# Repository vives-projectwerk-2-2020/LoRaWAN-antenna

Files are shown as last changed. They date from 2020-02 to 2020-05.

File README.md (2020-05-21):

# The LoRaWAN-antenna board

This is the explanation of how the antenna PCB board came. And how you can make one yourself.
This PCB described here must then be connected to the main PCB. Below you can see what it looks like.

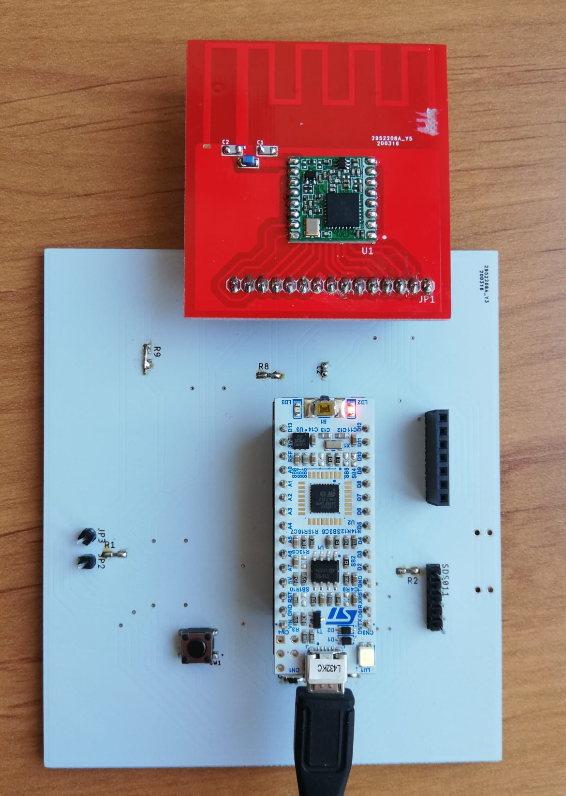
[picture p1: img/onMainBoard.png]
on main board


This Antenna on the board is based on [this](http://www.ti.com/lit/an/swra228c/swra228c.pdf) design.

## Explanation of the Antenna PCB board

Below you see the antenna board. The PCB antenna on this board is suitable for a frequency around 868MHz.

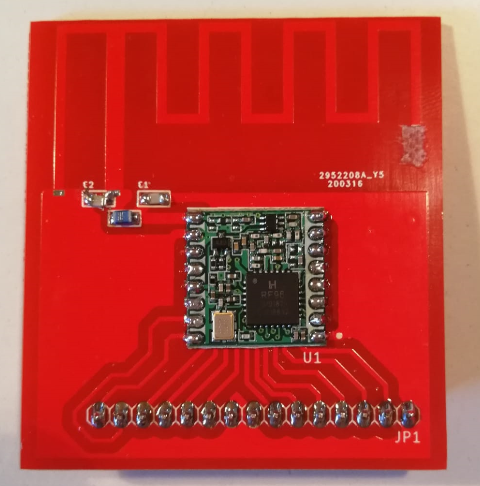
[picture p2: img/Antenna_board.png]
Antenna board


The antenna will work most efficiently if it is resonant. When it is resonant, the maximum power will be radiated by the antenna. If an antenna is not resonant, some of the power will not be transmitted. The power is reflected back to the transmitter (in our case the RF96 module).

Because of the reflection you have a RF power loss and you could damage the RF96 module and also reduce your transmission range.

You can solve this by doing 2 things:

* Adjust the length of the antenna and,
* add a matching network.

This is discussed below here.

### Adjust length

You can adjust the length here, by scratching away some copper at the end of the antenna. The total length of the last piece of the antenna is 1,25 cm (measured from the outer corner). See the image below for clarification.

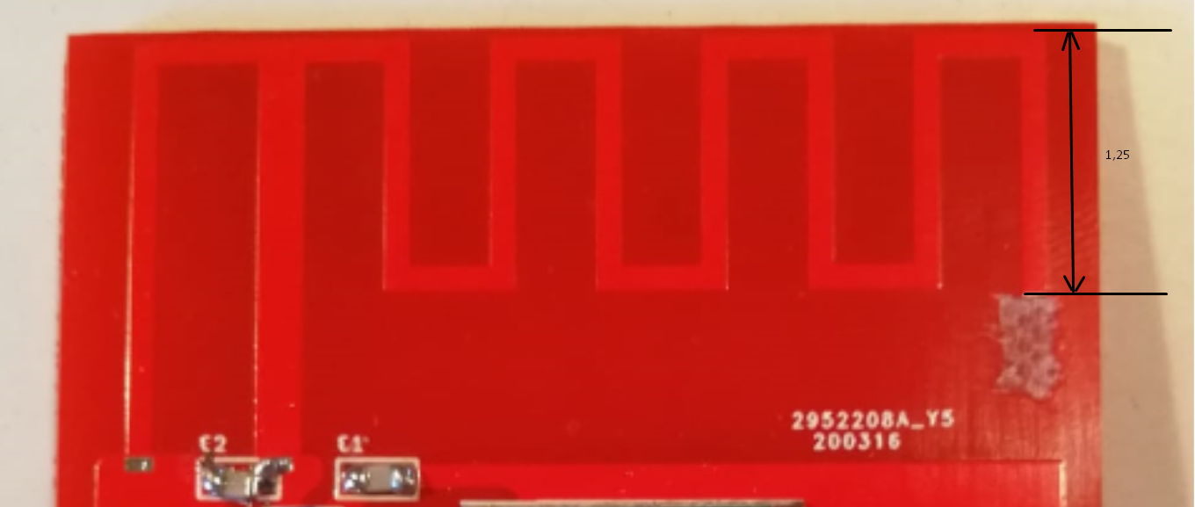
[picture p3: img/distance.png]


By adjusting the length of the antenna, the antenna is now al more suitable for 868MHz.

### Matching network

By adding a matching network now, we can improve the impedance of the antenna more.

The network for adjusting the impedance is a PI network. Below you can see the schematic of the network. The left side of the math unit is connected to the RF96 (the antenna output = pin 9). The right side of the unit is connected to the antenna.

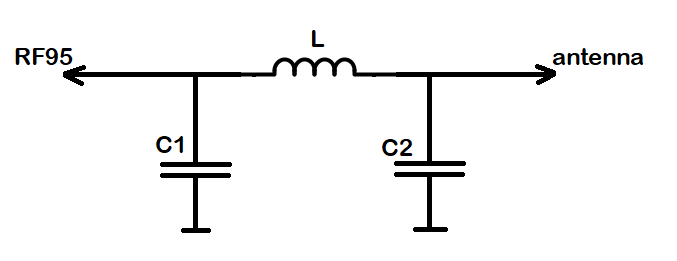
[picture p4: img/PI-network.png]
PI-network


You can observe the matching network below. This consists of 2 capacitors and 1 coil. The values of the capacitors are 2,2pF. The value of the coil is 12nH.

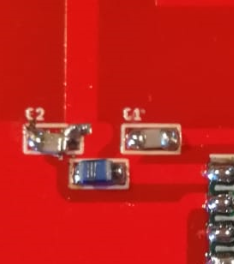
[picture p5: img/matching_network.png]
matching network


Due to mismatches in impedance, some of the signal is reflected. The ratio of the input to the reflected signal is called the Voltage Standing Wave Ratio (VSWR). This ratio can also be measured in dB, and expressed as Return Loss.

Below you can see that the VSWR at 868MHz is 1.112. This mean that you're return lose is 25.510dB. This is very good, because now less than 1% of the power goes back to the module. This means that more than 99% of the power is used for the communication.

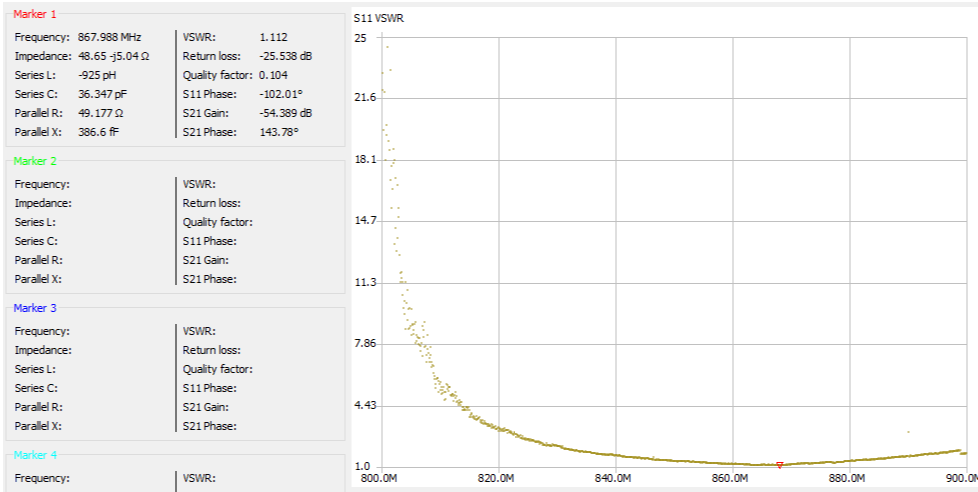
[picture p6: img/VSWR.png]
VSWR


The dimensions of the PCB are also very important. If the dimensions are different from here, you must again determine the length and the matching network.

### RF96

The RF96 module is a module suitable for ultra-long range spread spectrum communications. This module has a 20 dBm power amplifier. This means that you have an output power of 100mW. Because the impedance is now correct, all power will also be radiated effectively.

Below you see the RF95 module. All pins are brought out through the pins. Except the pin that goes to the antenna.
This PCB is then clicked on the main PCB.

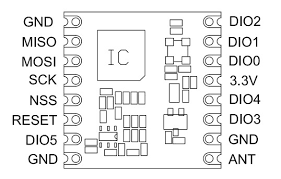
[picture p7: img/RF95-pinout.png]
RF95 pinout


### schematic and print in Eagle

Here you can see the schematic drawn in Eagle. At the top you see the pins, these are then connected to the main PCB. below that you see the RF96 chip.
In the middle you see the matching network, which ensures a correct impedance.
The square block on the right is the symbol for your antenna. It is a symbol whose foodprint is the shape of the antenna.

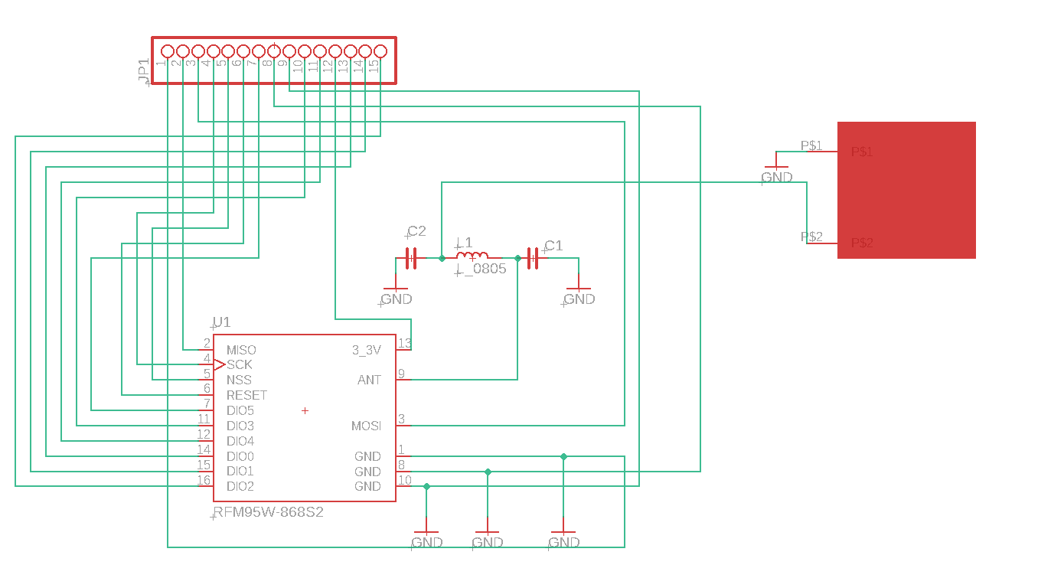
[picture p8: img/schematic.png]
schematic


Below you can see what the PCB looks like in eagle.

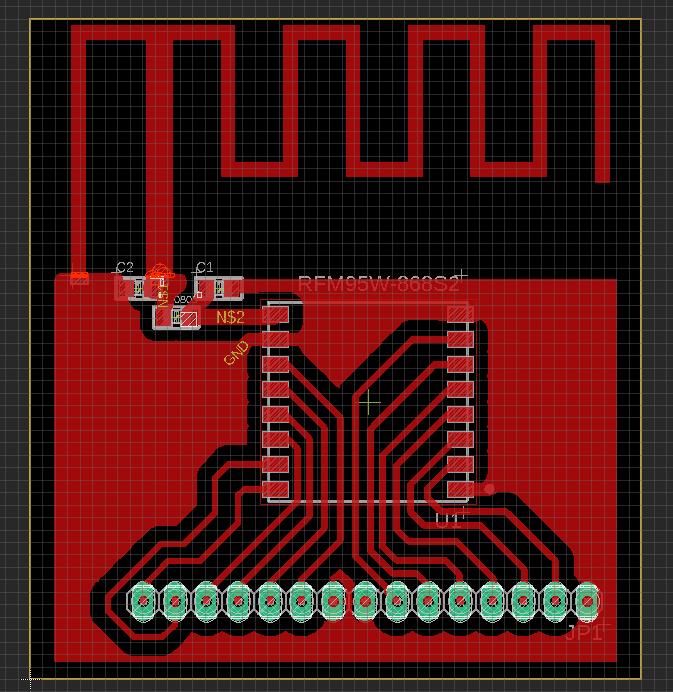
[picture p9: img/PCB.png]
PCB


### tests that happened

You can view the tests that happened in the folder "testing".

## Make it yourself

### Develop the PCB

First you need to develop the PCB. You can do this by sending a zip to a manufacturer. Like for example with this manufacturer([JLCPCB](https://jlcpcb.com/)).
The ZIP file is located here in the root and is called 'LoRaWAN_antenna.zip'. You can download and upload this on the manufacturer's website. If you want to make changes to the PCB you can edit it in the folder 'PCB-antenna-eagle'.

### Order the components

Then you have to order the components. These are the components:

* [coil (12nH)](https://be.farnell.com/te-connectivity/36502a12njtdg/inductor-12n-5-0805-case/dp/1265504?st=)
* [capacitors (2.2pF)](https://be.farnell.com/vishay/vj0805a2r2bxapw1bc/cap-2-2pf-50v-c0g-np0-0805/dp/2896503?st=)
* [RF96 module](https://www.digikey.be/product-detail/en/seeed-technology-co.,-ltd/109990166/1597-1488-ND/7033232?utm_adgroup=RF%20Transceiver%20Modules&utm_source=google&utm_medium=cpc&utm_campaign=Shopping_Product_RF%2FIF%20and%20RFID&utm_term=&productid=7033232&gclid=CjwKCAjwqpP2BRBTEiwAfpiD-0hUd9VhSiN13Y9OhOWbJ38YxABk0f2ujbqdI1xJR1xy0auqC77hRBoC65kQAvD_BwE)
* [male pins](https://be.farnell.com/harwin/m20-9990846/connector-header-tht-2-54mm-8way/dp/1022257)

for 1 PCB you need 2 capacitors, 1 coil, 1 RF95 module and 15 male pins.

### Solder everything together

If you then have your PCB and components, you can start soldering.
You should not scratch the antenna anymore, I have already adjusted this in the last version.
For soldering it is best to start with the RF96 module and then the capacitors and the coil.
Then solder the pins on the last.

## Placing the installation

If you have connected all the boards(main + solar + antenna), you can place this where you want.
There are some things to keep in mind:

* Place the installation in a place where connections can be made to a gateway. On [this](https://www.thethingsnetwork.org/map) map you can see where there is a gateway. If you want a map where you can see the range, it is best to use [this map](https://ttnmapper.org/).

* Place the installation as high as possible. The higher, the fewer obstacles in the way and the greater the chance of connecting to a gateway.

* Do not place the antenna under the solar panels or next to the solar panels. Because this will ensure that a lot of your range is gone.

* The box you use should not be made of metal or a substance containing metal. [This](http://www.farnell.com/datasheets/2360495.pdf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) box is ideal. The material from which the box is made is Polycarbonate. This does not contain metal.

* The box with should be placed freely, not against a wall. Also make sure you are at a certain height.

* Make sure the box is not completely closed. It is best to make 1 or 2 small holes at the bottom so that moisture can escape if condensation forms.

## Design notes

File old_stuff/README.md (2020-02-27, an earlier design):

Op PCBs wordt meestal een 4de golf antenne gebruikt, belangrijk hierbij zijn:
* de antenne lengte
* de antenne voeding
* vorm en grootte van het grondvlak en retourpad (hoe groter oppervlak, hoe lager de resonatiefrequentie)
* als de antenne in een plastieken omhulsel geplaatst wordt, dan verlaagd ook de resonatiefrequentie.

De meeste Gateways staan in centrum brugge. Er staat ook 1 op het zwin.
Als er een node in zeebrugge geplaatst wordt, dan is de dichste de gateway aan het zwin (5km)
De antenne van de node moet dus 5 km kunnen overbruggen.

# gevonden ontwerpen:


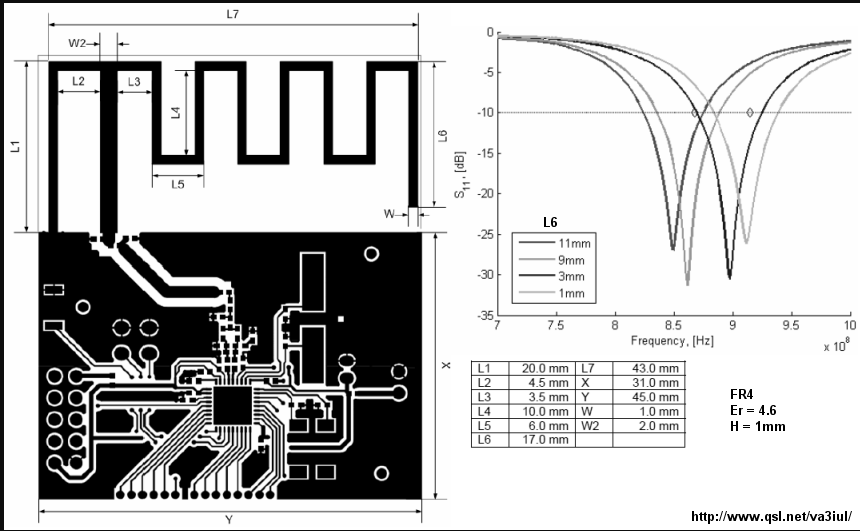
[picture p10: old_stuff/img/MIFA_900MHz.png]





overzicht van verschillende antennes van ti:
http://www.ti.com/lit/an/swra351a/swra351a.pdf

https://www.ti.com/lit/an/swra227e/swra227e.pdf 

http://www.ti.com/lit/an/swra416/swra416.pdf

http://www.ti.com/lit/an/swra228c/swra228c.pdf

https://www.cypress.com/file/136236/download

https://eth0maz.wordpress.com/2016/12/05/lorawan-node-with-onboard-antenna/

Het grootte nadeel aan een PCB antenne is dat het bereik ervan beperkt is. Als er een node wordt opgesteld in zeebrugge moet er zeker 5km overbrugt worden met de antenne. Met een PCB-antenne is dit bijna onmoggelijk.
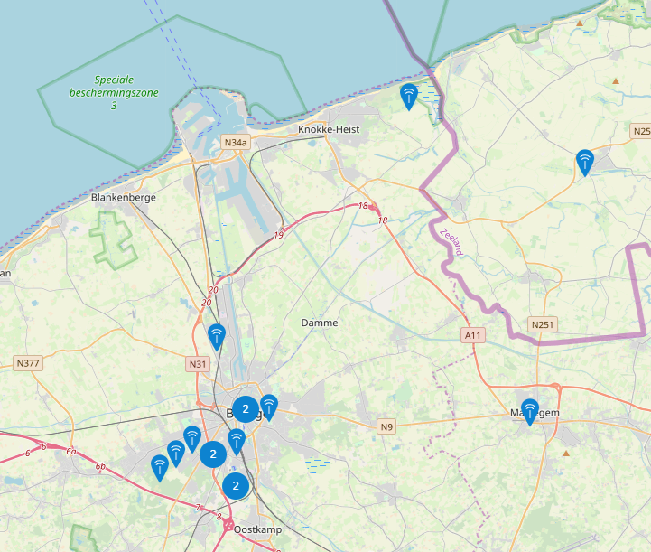
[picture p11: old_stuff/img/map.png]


verschillende soorten PCB antennes:

LOOP
* hoe groter de loop, hoe beter het werkt
* alle omtrekken kleiner dan 0.1 golflengte zijn nutteloos. Voor 868MHz is de golflente 0.35m = 35cm (redelijk groot)
* zeer onefficiënt

PATCH
* breedte van een het vierkant is dicht bij ((golflengte/2)/vierkantswortel van dielectric constant). de breedte zal dus rond de 9cm liggen.
* bandbreedte is zeer smal

INVERTED-F
* groot ground plane nodig

MEANDER LINE
* kleiner bereik

file:///C:/Users/laura/Downloads/Antenna_Reference_Design_Guide_ISM.pdf

Het probleem bij PCB antennes is dat je een richtingseffect krijgt, dat de antenne niet in alle richtingen even goed zal kunnen ontvangen.

PCB antenne: (straalt niet in alle richtingen even veel uit, heeft een richtingseffect)



# dipool: (straalt mooi in alle richtingen evenveel uit)



# biquad antenne: 
stralingspatroon is beter dan van de eerste pcb antenne, dit is niet echt een pcb antenne



op thingiverse staat er een ontwerp dat je kan printen, en dan zelf er een draad in de gleuven legt, maar de afmetingen zijn ook te groot.(https://www.thingiverse.com/thing:2221922 )

# gasket antenne




voordeel: heeft de beste stralingspatroon, van alle platte antennen.

nadeel: moeilijker te tekenen

nadeel:de afmetingen van de antenne zijn te groot, om in de behuizing te plaatsen

-> niet bruikbaar voor onze opstelling.

# koch antenna


# inverted F
* terug te groot voor onze opstelling (20cm breedte, volgens mathlab)

# commercieel
https://www.amazon.co.uk/Lillyelectronics-Q-BAIHE-865-868MHz-Antenna-Connector/dp/B017N761JQ 

# met mahtlab
https://nl.mathworks.com/products/antenna.html

# vereisten
* De radiaton van de antenne moet Omnidirectional zijn, dit wil zeggen dat de antenne in alle richtingen even veel uitzendt/ontvangt. Dit is nodig in ons geval, omdat de gateway overal kan staan.
* De polarizatie van de antenne van de node wordt best verticaal genomen. Dit omdat de meeste gateways ook verticaal werken.
* De bandbreedte, Als de bandbreedte zeer smal is dan is deze zeer moeilijk te maken, maar heb je wel een optimaal ontvangst.
* hoge efficienty, bij een hoge efficienty zijn er niet veel verliezen in de antenne.

file:///C:/Users/laura/Downloads/HF-Praxis7-2015%20V.pdf

http://www.ti.com/lit/an/swra227e/swra227e.pdf

# antenne die zal worden gemaakt worden

http://www.ti.com/lit/an/swra228c/swra228c.pdf
https://github.com/cernohorsky/LoRa-Node

Op deze ontwerpen zal ik mij baseren bij het tekenen en onwerpen van de PCB antenne.

Deze antenne is niet omnidirectioneel, waardoor je een richtingsantenne krijgt. Het is namelijk bijna onmogelijk om een pcb antenne te vinden/ontwikkelen die omnidirectioneel is en nog in de doos zou kunnen.
De afmetingen van deze antenne zijn wel klein genoeg om in de doos te kunnen plaatsen, vandaar de keuze.

## verdere stappen

doorzichtige mika en fotogevoelige printplaat gaan kopen, zodat er kan getest worden als dit ontwerp effectief goed zal werken.
ook de smd condensators aankopen.

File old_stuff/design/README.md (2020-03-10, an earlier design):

# Design about the PCB antenna
## pi-network
Pi-network bestaat uit C3, C4 en L1. (footprint 0805), waarden zullen moeten gemeten worden als de antenna ontworpen is. Dit om ervoor te zorgen dat je een juiste impedantie aanpassing van 50 ohm hebt.



## Eagle schema

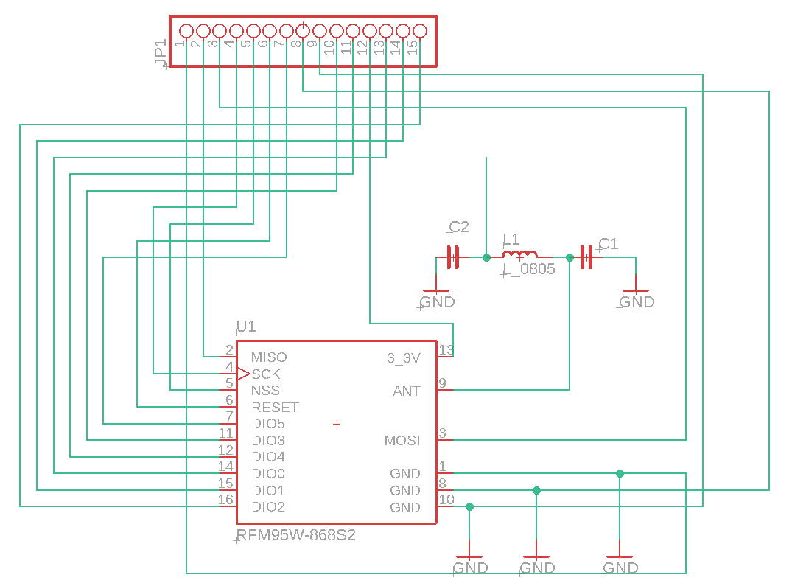
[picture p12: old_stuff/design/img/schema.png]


## Eagle print

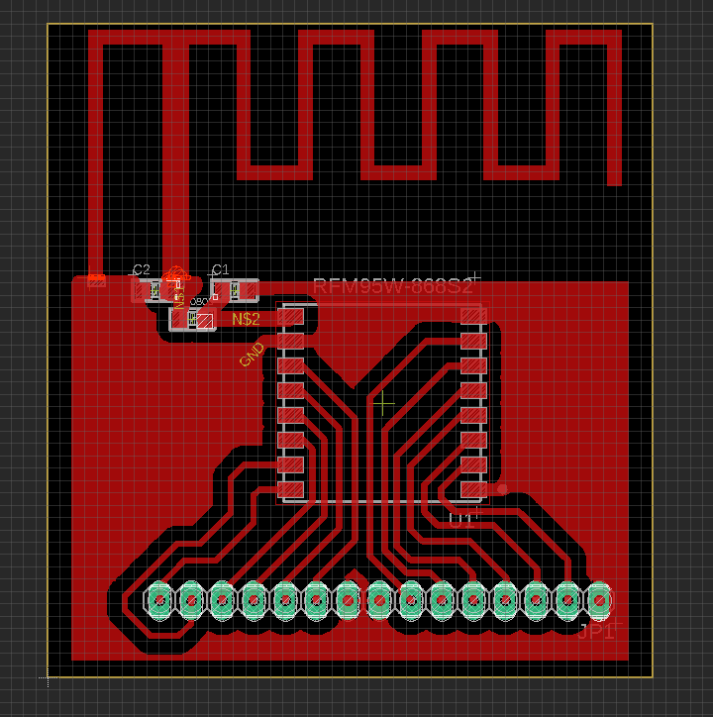
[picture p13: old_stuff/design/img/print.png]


## printen op mika
De transparant maken in mislukt. Er werden verschillende instellingen bij de printer geprobeerd.





Er zal dus een print besteld worden, in plaats van zelf te etsen.

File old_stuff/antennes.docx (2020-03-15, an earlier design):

Hoe dichter het getal VSWR bij ‘1’ is hoe beter dat die antenne is op die frequentie.

S11 (VSWR) | Return loss (dB)
1.001 | 66.025
1.1 | 26.444
1.2 | 20 | 1% reflectie, 99% van het vermogen gaat effectief in de antenne
2.3 | 8 | 16% reflectie, 84% van het vermogen gaat in de antenne
6 | 3 | 50% reflectie, 50% gaat in de antenne
Oneindig (>20) | 0 | 100% reflectie, er gaat geen vermogen in de antenne

je kan ook direct de return loss meten, maar op de S11 grafiek kan je de dalen en pieken mooier zien.

- kleinste antenne
  - 3.121 VSWR

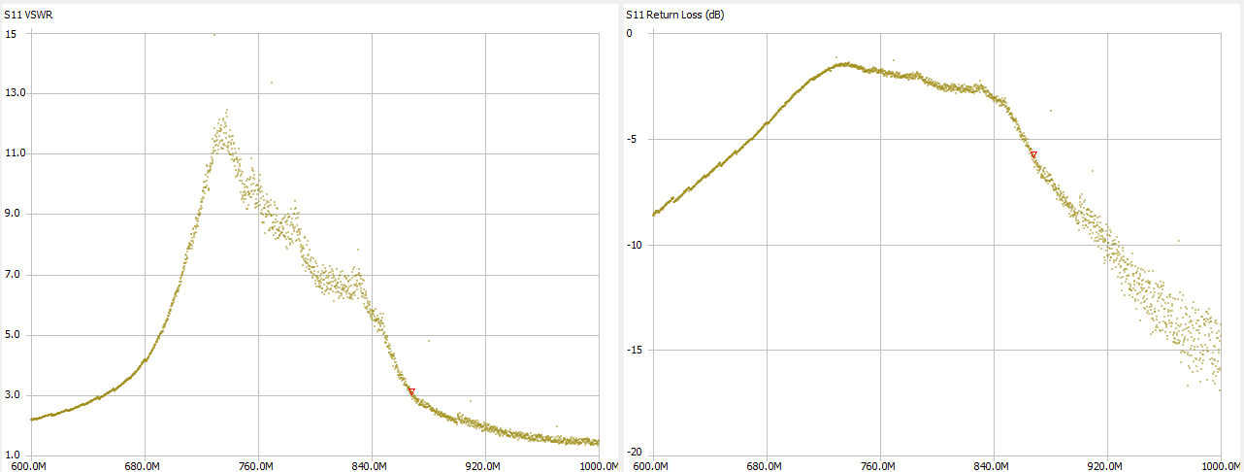
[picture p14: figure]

- kleinste antenne onder een hoek
  - 1.029 VSWR

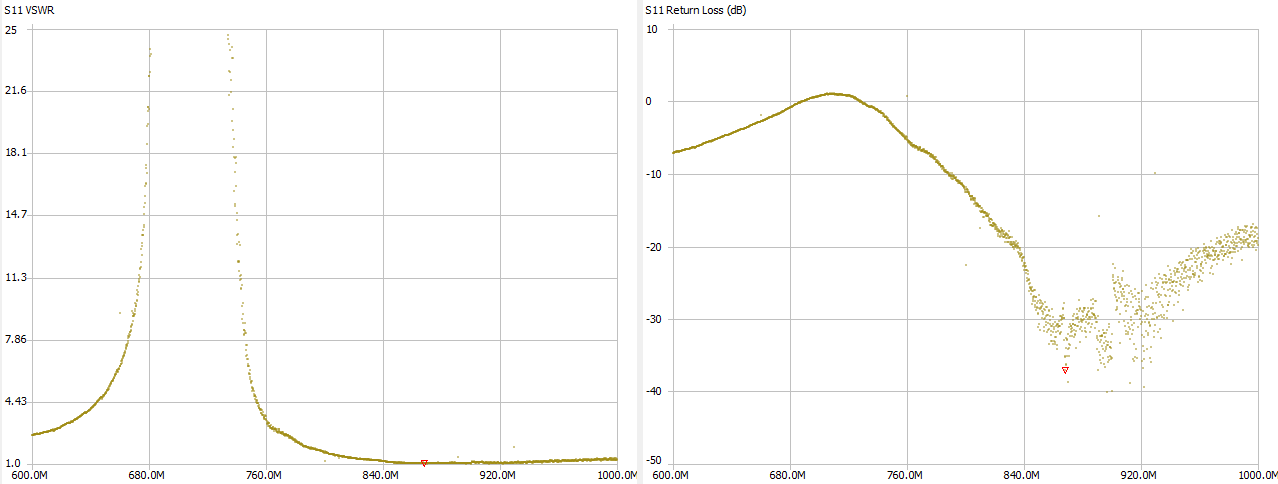
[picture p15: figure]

- 2de kleinste antenne (de fijne)
  - 1.177 VSWR

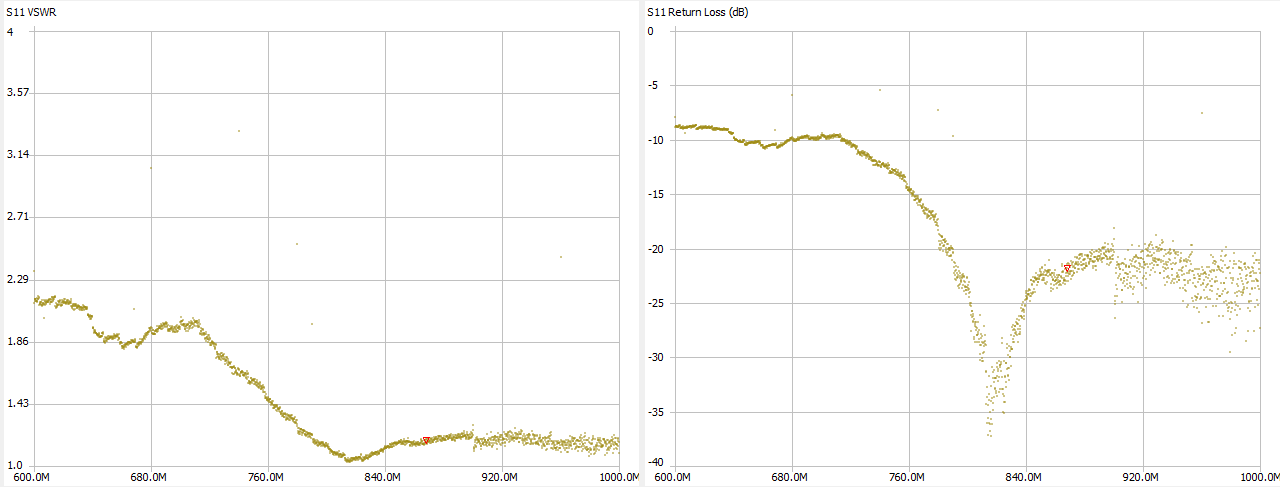
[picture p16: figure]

- 2de kleinste antenne (de dikke)
  - 1.168 VSWR

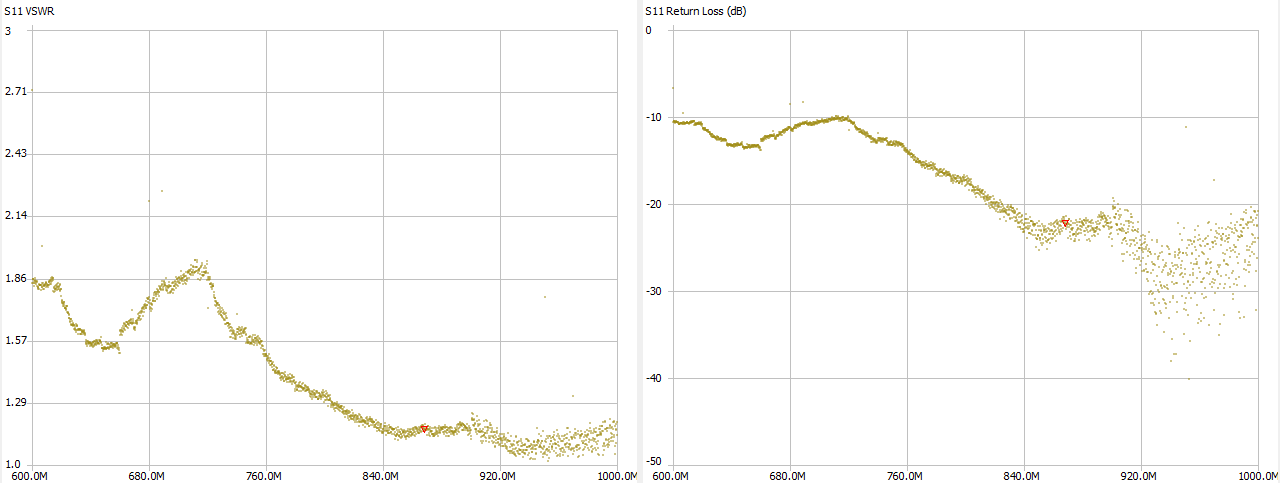
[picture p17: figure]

antenne die op het lorabordje aanwezig was

- -8.655 VSWR

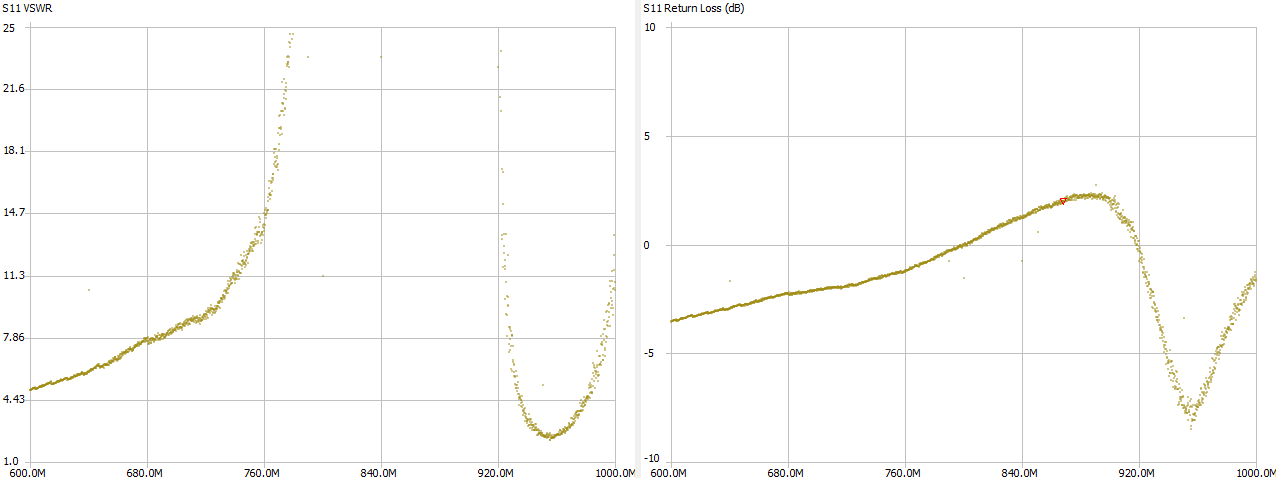
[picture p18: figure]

antenne met 2 rode cirkels vanboven

- 6.655 VSWR

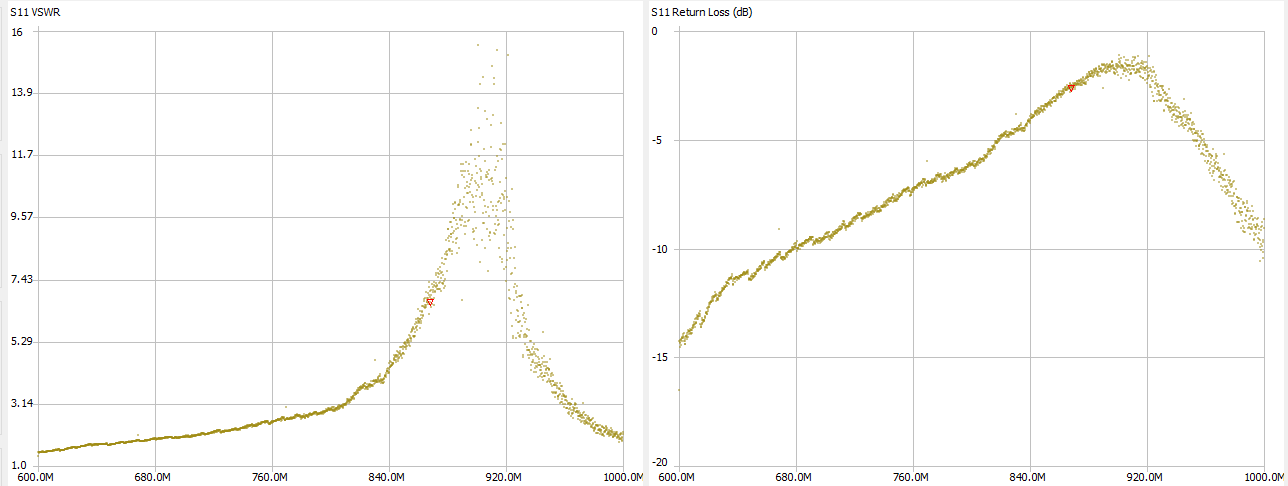
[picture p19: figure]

- 2de grootste antenne
  - 6.235 VSWR

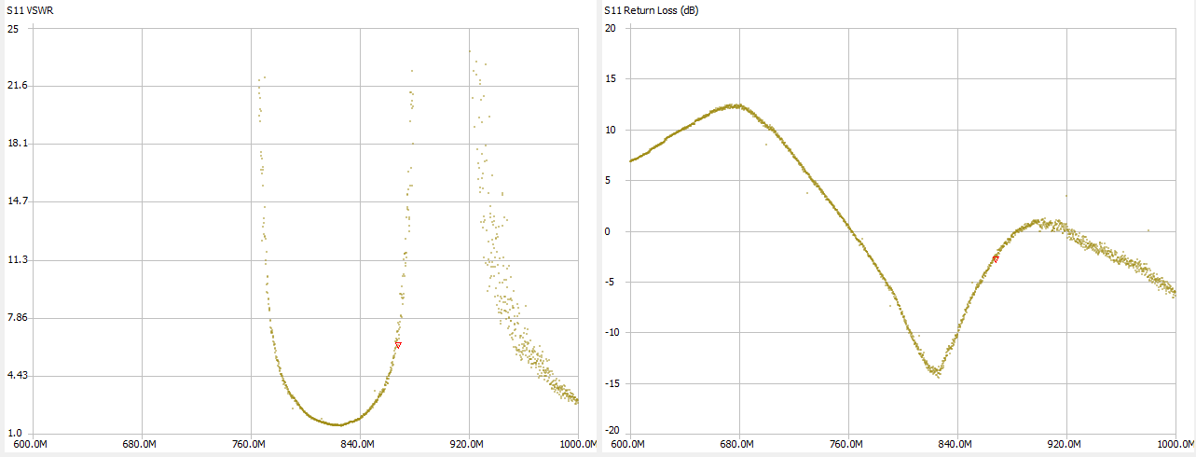
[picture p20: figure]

- grootste antenne
  - 605.667 VSWR = oneindig

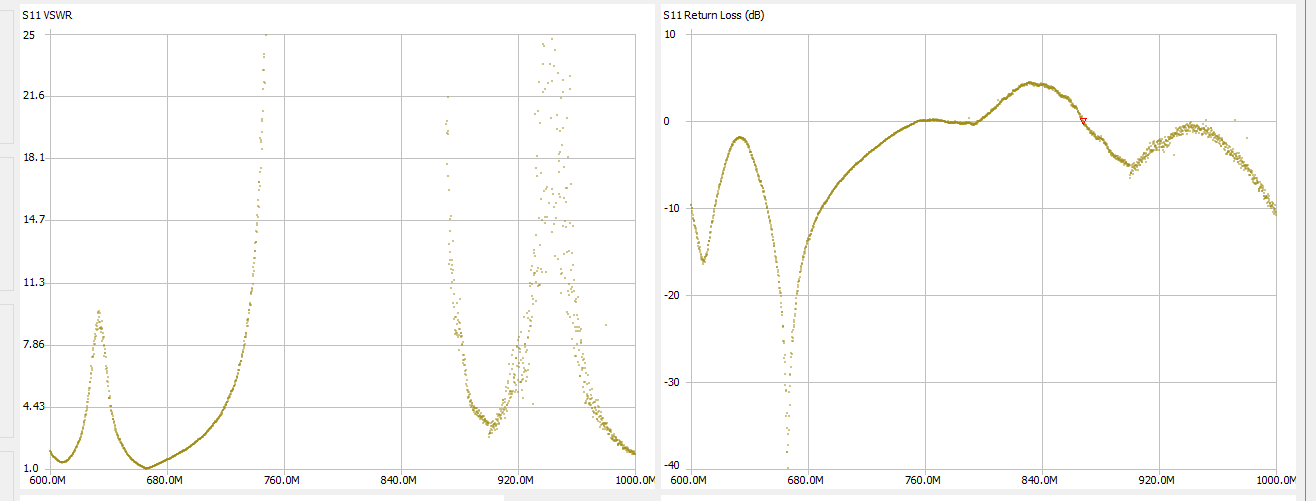
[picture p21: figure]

PCB antenne VSWR

- -2.176 VSWR

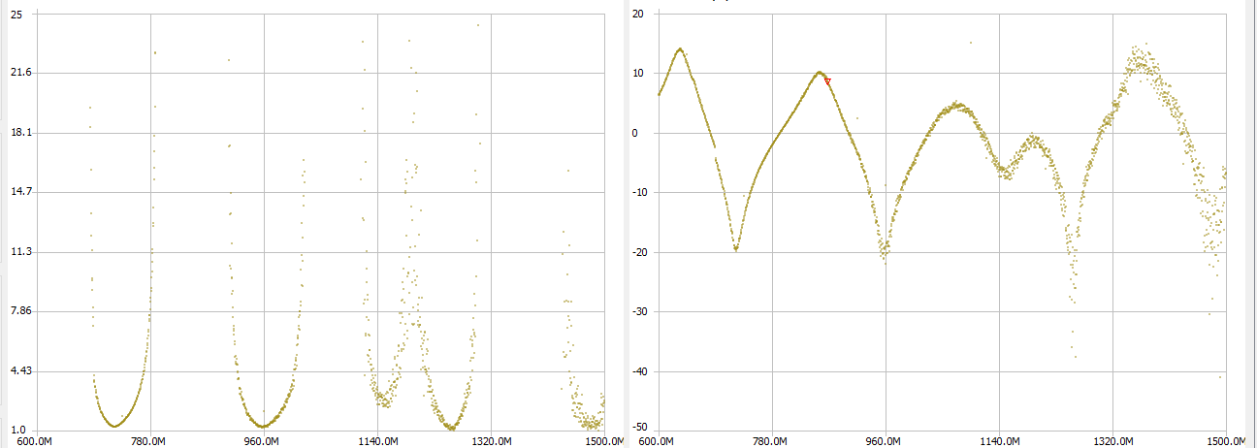
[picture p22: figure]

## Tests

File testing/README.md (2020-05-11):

# TESTING

## Testing the right length and values for the matching network

Soldered on C1 and C2 capacitors of 2.2pF. A value of 12nH was taken for the coil.
The total length of the last piece of the antenna is 1.25 cm. (measured from the outer corner)

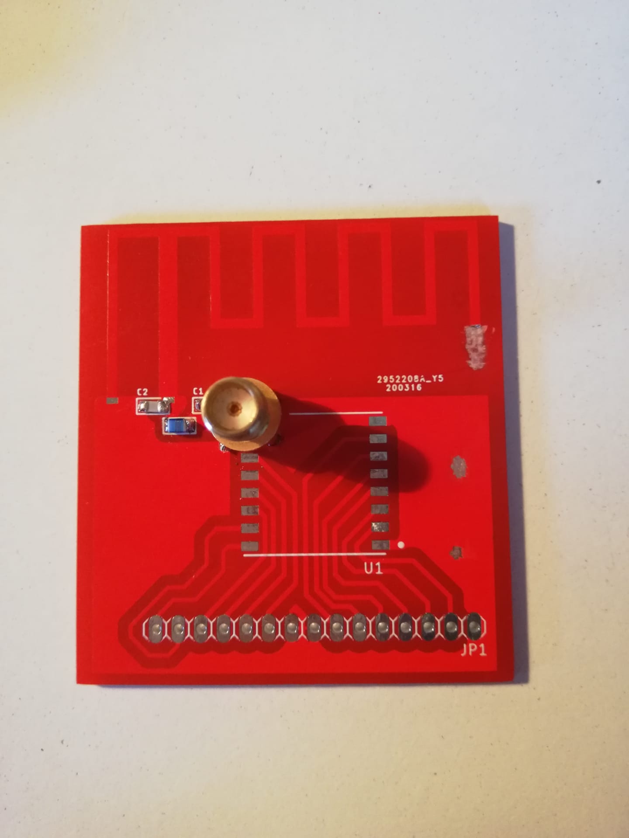
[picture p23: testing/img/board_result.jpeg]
result


In the figure below you can see that at 868MHz the VSWR is 1.112. This is 0.28% reflection of your power sent to your antenna.

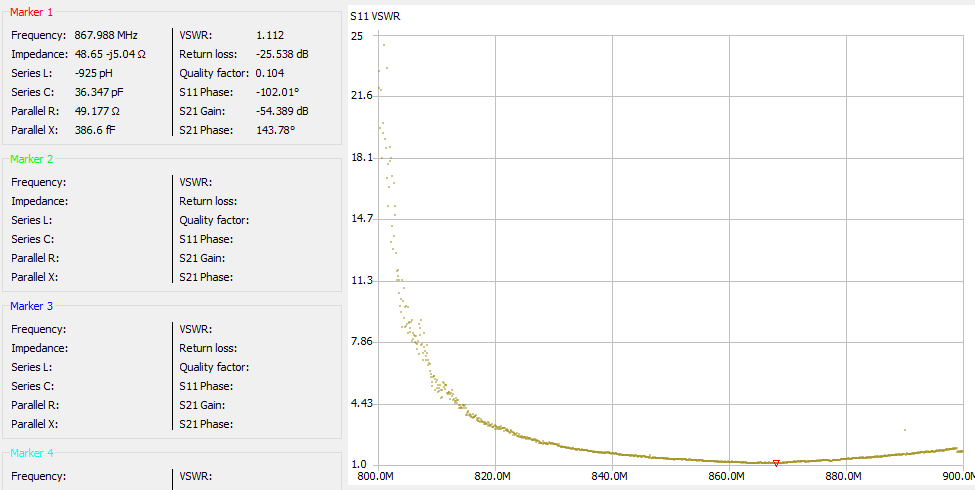
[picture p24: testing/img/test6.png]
test6


## Making the board with lora module

The antenna scratched to the correct length and soldered the components on it.
The pins are properly soldered so that they can be connected to the main board.
This is the frond:

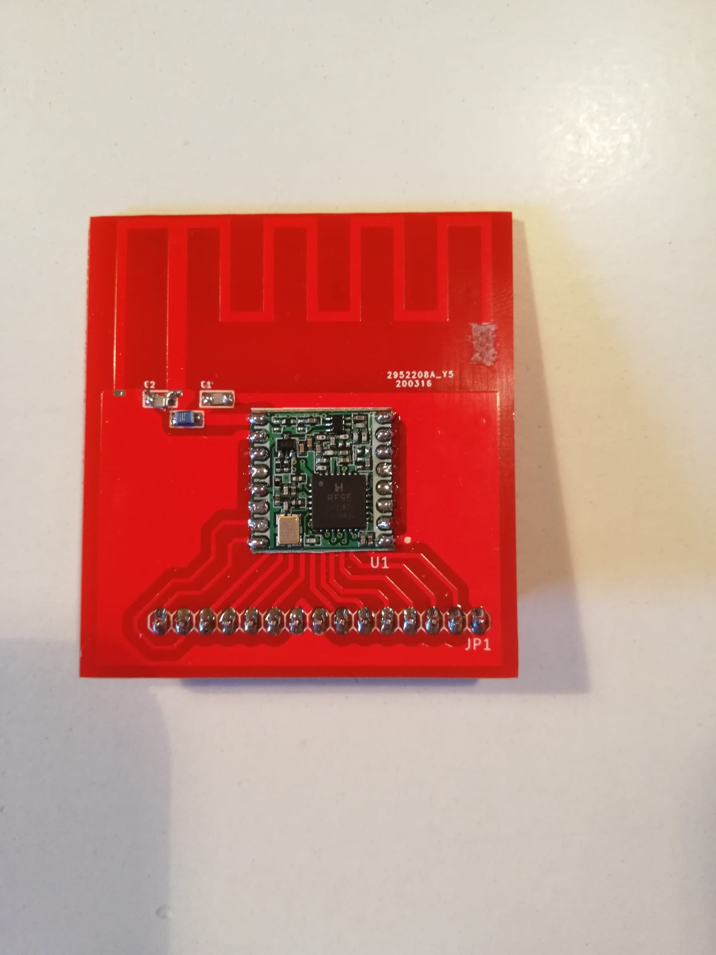
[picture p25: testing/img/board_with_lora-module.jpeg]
front


And this is the back:

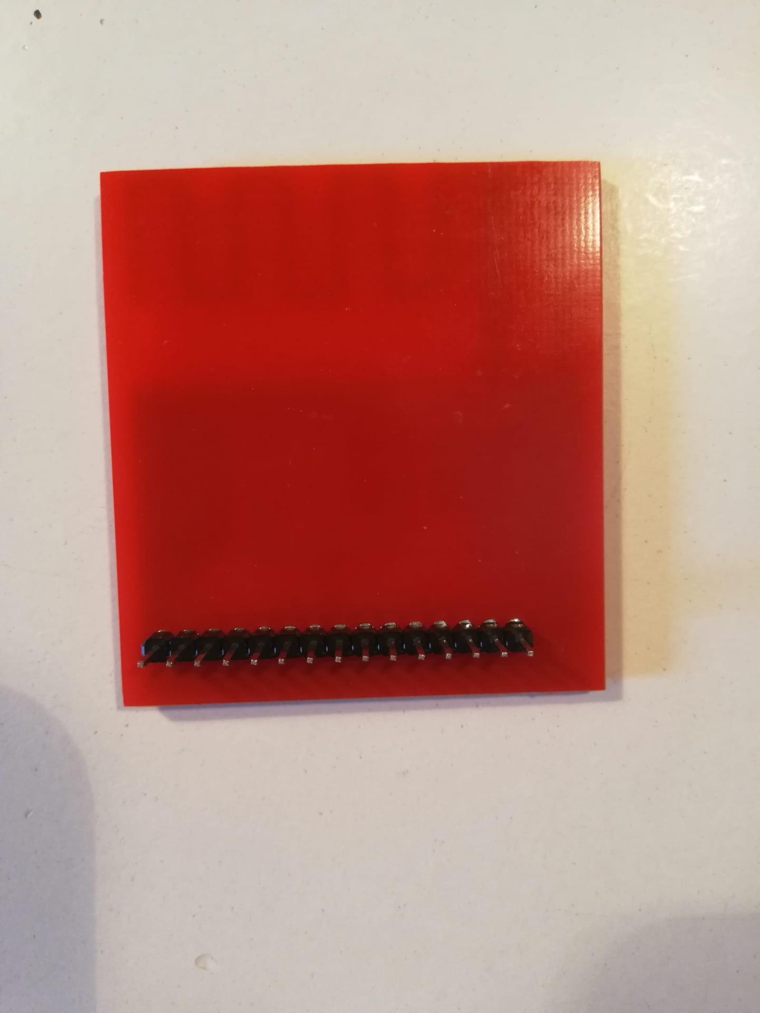
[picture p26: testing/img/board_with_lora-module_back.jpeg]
back


## Testing the board with the main board

The PCB board connected to the main board. Then loaded the software into the Nucleo. The software comes from here: [LoRaWan-example](https://github.com/vives-projectwerk-2-2020/LoRaWAN-example).

In the setting.h something has to be changed about the pins. This is how it should look for the little nucleo:

pins_settings.h

Added a device on TTN and put the keys in a file settings.h as described in the LoRaWan-example.

Here you can see the communication over the port with Putty:

putty

Below you can see that there is a connection with TTN:

status_connection

And here you see 2 boards connected to each other:

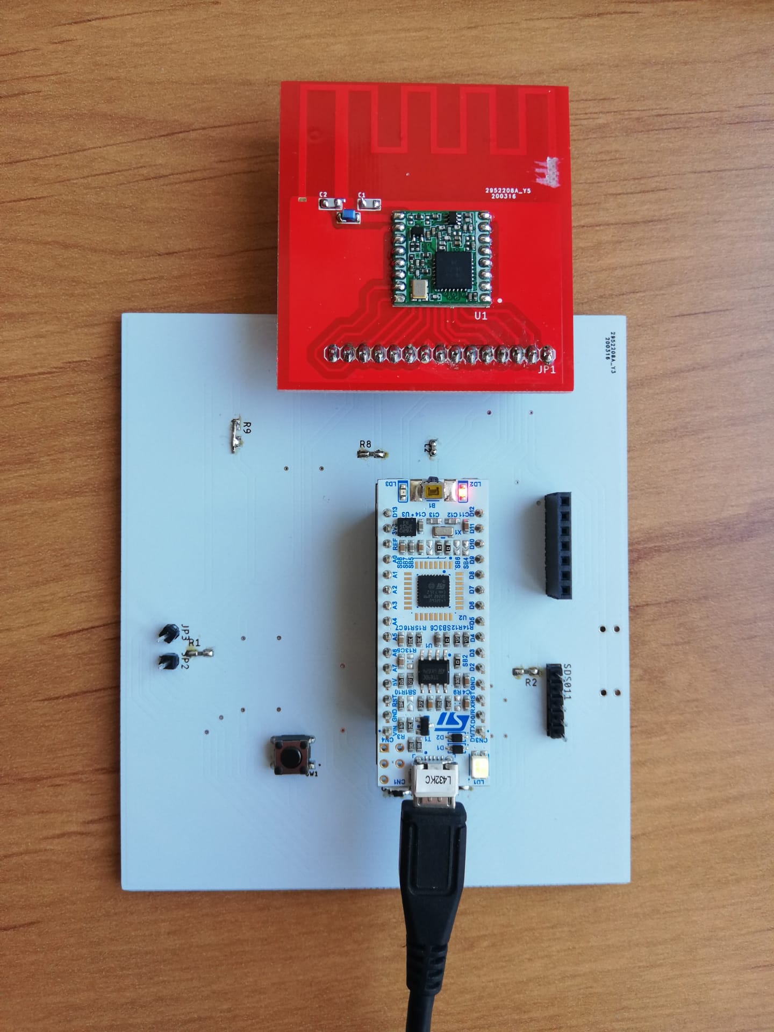
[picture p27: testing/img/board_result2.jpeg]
result


## Test the range with original antennas

On the following images you can see where there was connection with TTN. The gateway I use is a Dragino LG02, at the moment the original antennas are still on it.

point 1: 1,1km. The antennas see each other here.

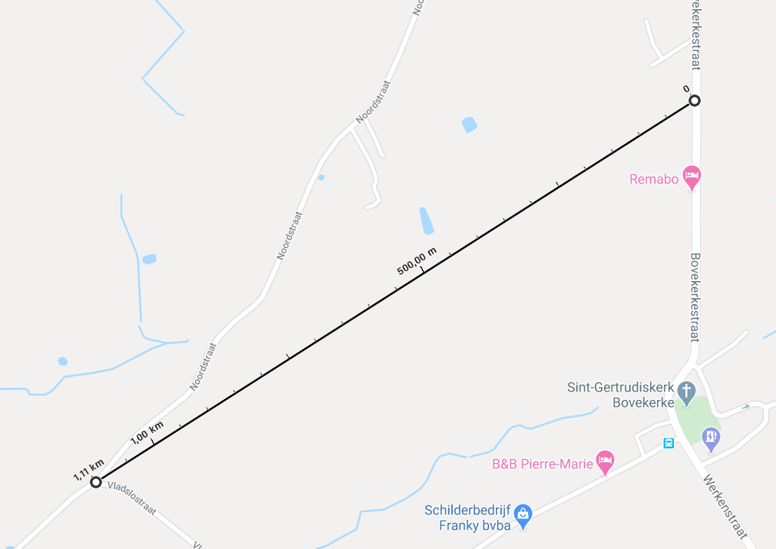
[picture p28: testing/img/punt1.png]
point1


point 2: 1,76km. The antennas did not see each other, there was a large concrete storage place in front of it.

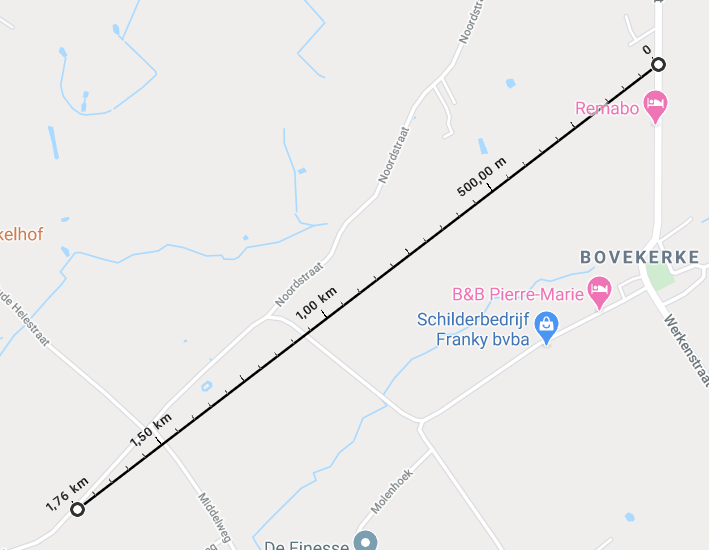
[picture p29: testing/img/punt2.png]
point2


## Test the range with a better antenna on the gateway

The antenna is now 10m high. The test setup can be found in the following 2 images.
In the box is the gateway (LG02 from dragino). One of the original antennas is disconnected and connected to a bigger antenna. This is an omnidirectional antenna with 3dB gain.
The antenna is mounted via a bracket on the pole.

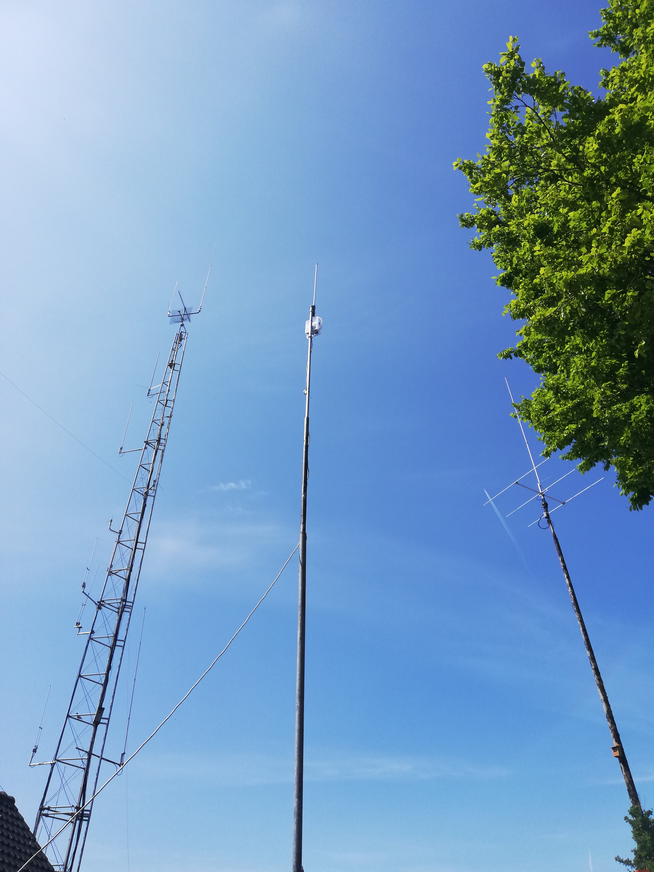
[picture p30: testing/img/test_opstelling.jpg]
test

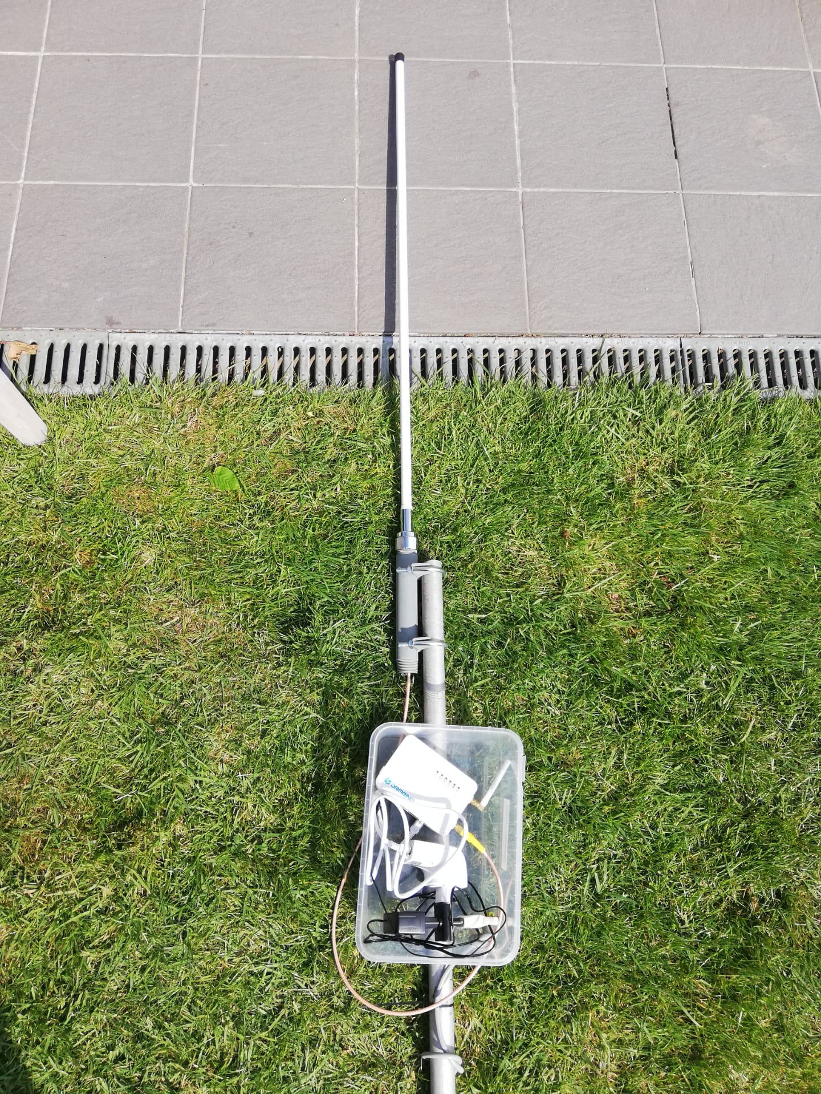
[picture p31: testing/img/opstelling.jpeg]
test


The range is now much better, it is doubled. Distances of 3.20 km are now possible, you can see this on the map below.
The points below are points where connections to TTN could be made. At the points you can always see the distance in bird's eye view.

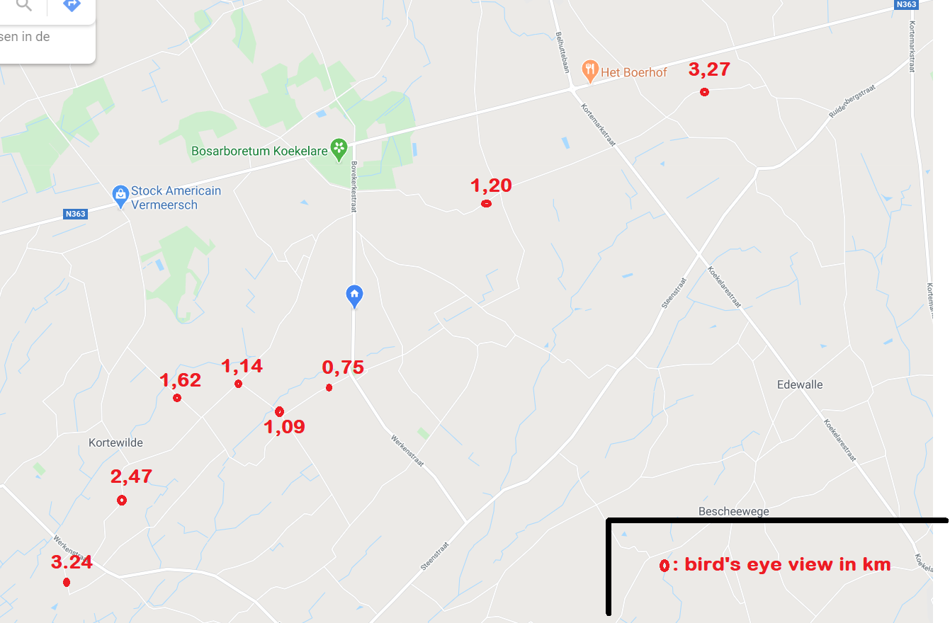
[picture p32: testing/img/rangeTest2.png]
rangeTest2Map


## Test the different between the PCB antenna and the previous antenna

Below you see the circuit:

circuit

Here you can see where there was signal with TTN. You can see that the range with that previous antenna is much smaller.
This means that the PCB antenna is an improvement on the previous antenna.

BadAntenna

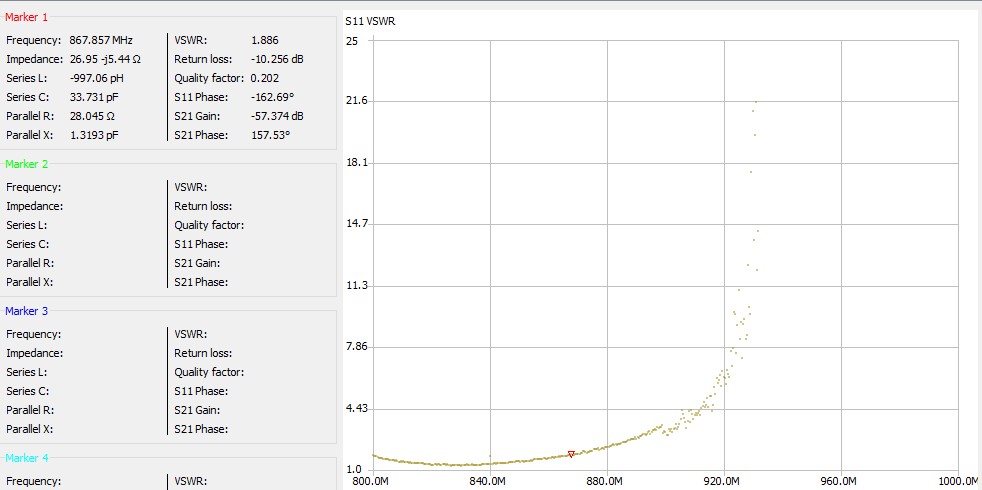
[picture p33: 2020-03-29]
testing/img/test1.png

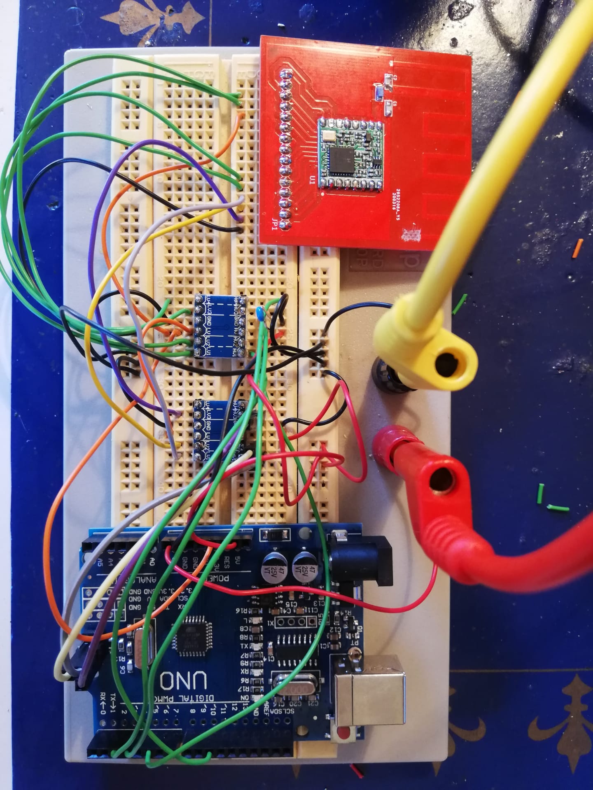
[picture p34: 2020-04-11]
testing/img/arduino.jpeg

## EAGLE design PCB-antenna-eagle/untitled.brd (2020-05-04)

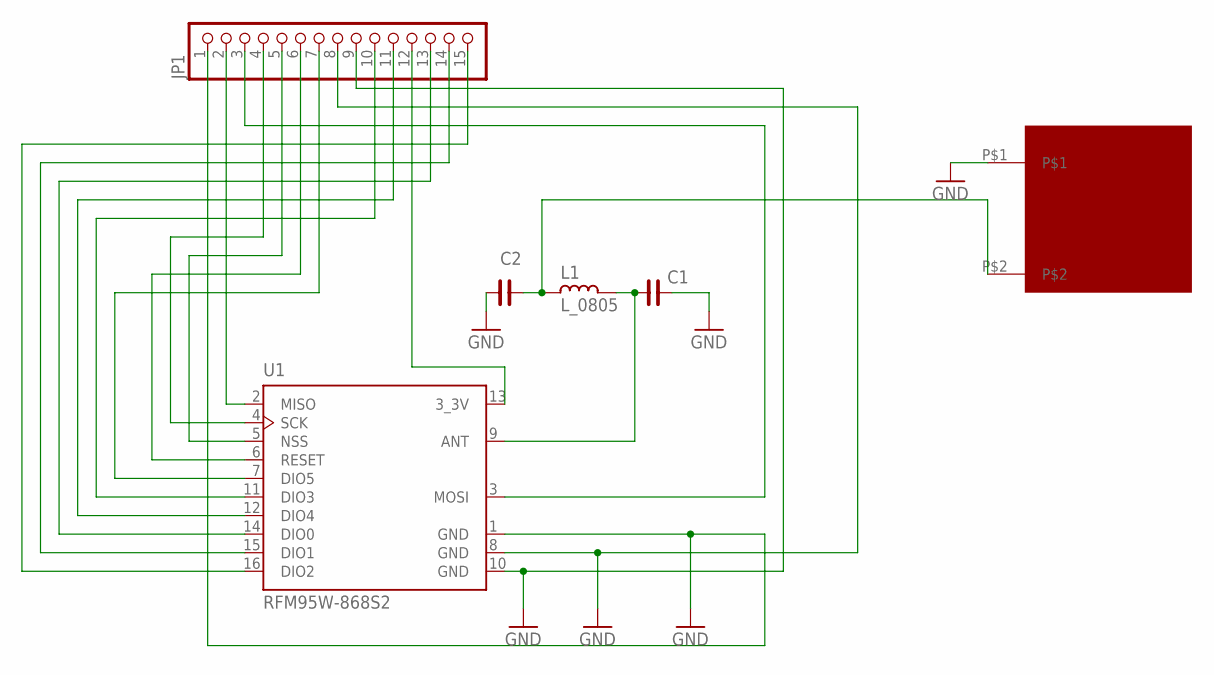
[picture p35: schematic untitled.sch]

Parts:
C1, C2: C_0805; C0805
JP1: PINHD-1X15; 1X15
L1: L_0805; L0805
U1: RFM95W-868S2; XCVR_RFM95W-868S2
U$1: 868

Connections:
GND: C1.2, C2.1, JP1.1, JP1.8, JP1.9, U1.1 (GND), U1.8 (GND), U1.10 (GND), U$1.P$1
unnamed: C2.2, L1.2, U$1.P$2
unnamed: C1.1, L1.1, U1.9 (ANT)
unnamed: JP1.2, U1.2 (MISO)
unnamed: JP1.3, U1.3 (MOSI)
unnamed: JP1.4, U1.4 (SCK)
unnamed: JP1.5, U1.5 (NSS)
unnamed: JP1.6, U1.6 (RESET)
unnamed: JP1.7, U1.7 (DIO5)
unnamed: JP1.10, U1.11 (DIO3)
unnamed: JP1.11, U1.12 (DIO4)
unnamed: JP1.12, U1.13 (3_3V)
unnamed: JP1.13, U1.14 (DIO0)
unnamed: JP1.14, U1.15 (DIO1)
unnamed: JP1.15, U1.16 (DIO2)

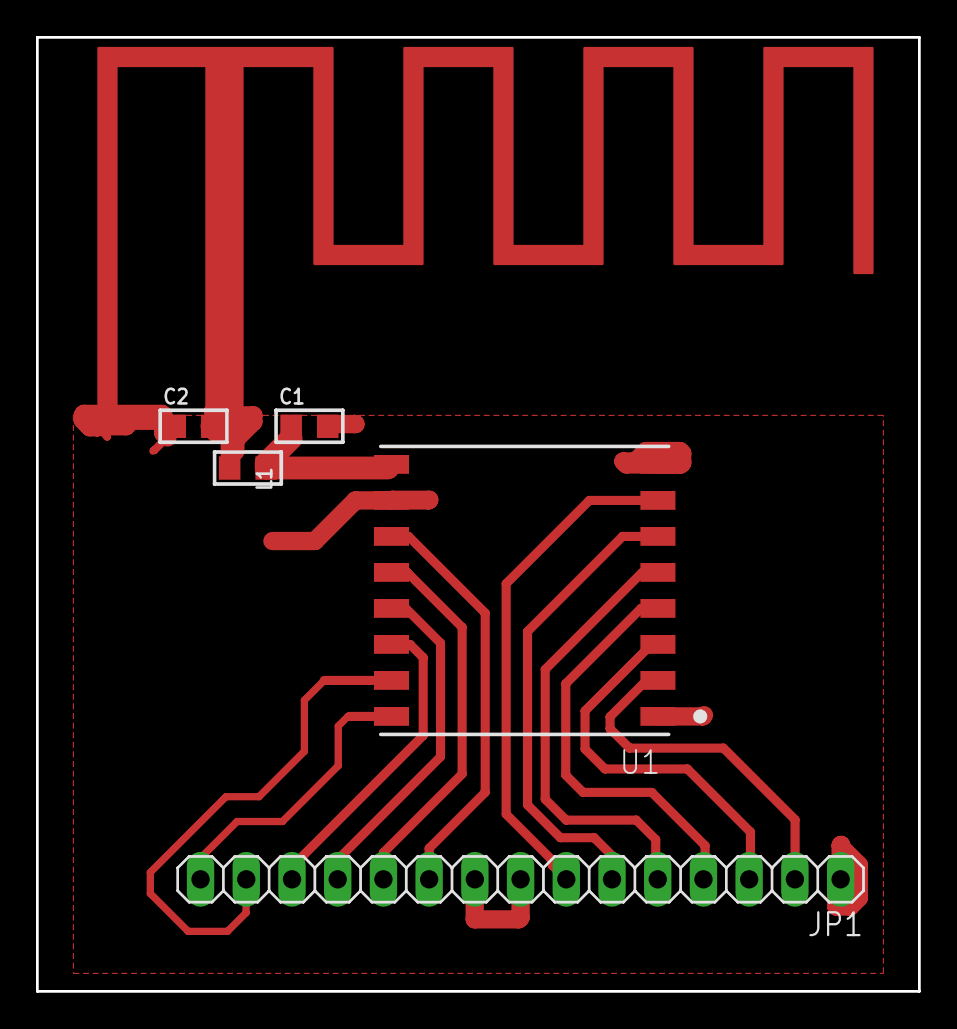
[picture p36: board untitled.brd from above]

Board: 2 copper layers, 49.0 x 53.0 mm, 6 parts (0 on the bottom side), 15 nets.

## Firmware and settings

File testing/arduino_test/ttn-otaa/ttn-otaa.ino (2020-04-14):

/*******************************************************************************
 * Copyright (c) 2015 Thomas Telkamp and Matthijs Kooijman
 * Copyright (c) 2018 Terry Moore, MCCI
 *
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
 * This example sends a valid LoRaWAN packet with payload "Hello,
 * world!", using frequency and encryption settings matching those of
 * the The Things Network.
 *
 * This uses OTAA (Over-the-air activation), where where a DevEUI and
 * application key is configured, which are used in an over-the-air
 * activation procedure where a DevAddr and session keys are
 * assigned/generated for use with all further communication.
 *
 * Note: LoRaWAN per sub-band duty-cycle limitation is enforced (1% in
 * g1, 0.1% in g2), but not the TTN fair usage policy (which is probably
 * violated by this sketch when left running for longer)!

 * To use this sketch, first register your application and device with
 * the things network, to set or generate an AppEUI, DevEUI and AppKey.
 * Multiple devices can use the same AppEUI, but each device has its own
 * DevEUI and AppKey.
 *
 * Do not forget to define the radio type correctly in
 * arduino-lmic/project_config/lmic_project_config.h or from your BOARDS.txt.
 *
 *******************************************************************************/

#include <lmic.h>
#include <hal/hal.h>
#include <SPI.h>

//
// For normal use, we require that you edit the sketch to replace FILLMEIN
// with values assigned by the TTN console. However, for regression tests,
// we want to be able to compile these scripts. The regression tests define
// COMPILE_REGRESSION_TEST, and in that case we define FILLMEIN to a non-
// working but innocuous value.
//
#ifdef COMPILE_REGRESSION_TEST
# define FILLMEIN 0
#else
# warning "You must replace the values marked FILLMEIN with real values from the TTN control panel!"
# define FILLMEIN (#dont edit this, edit the lines that use FILLMEIN)
#endif

// This EUI must be in little-endian format, so least-significant-byte
// first. When copying an EUI from ttnctl output, this means to reverse
// the bytes. For TTN issued EUIs the last bytes should be 0xD5, 0xB3,
// 0x70.
static const u1_t PROGMEM APPEUI[8]={ 0xB0, 0xDA, 0x02, 0xD0, 0x7E, 0xD5, 0xB3, 0x70 };
void os_getArtEui (u1_t* buf) { memcpy_P(buf, APPEUI, 8);}

// This should also be in little endian format, see above.
static const u1_t PROGMEM DEVEUI[8]={ 0xEA, 0xDB, 0xCC, 0xDA, 0x9B, 0x9E, 0xE4, 0x00 };
void os_getDevEui (u1_t* buf) { memcpy_P(buf, DEVEUI, 8);}

// This key should be in big endian format (or, since it is not really a
// number but a block of memory, endianness does not really apply). In
// practice, a key taken from ttnctl can be copied as-is.
static const u1_t PROGMEM APPKEY[16] = { 0xFE, 0x09, 0x57, 0xD2, 0x71, 0x9A, 0x84, 0xBE, 0x05, 0xCF, 0x00, 0x38, 0xF8, 0xC9, 0x1F, 0x32 };
void os_getDevKey (u1_t* buf) {  memcpy_P(buf, APPKEY, 16);}

static uint8_t mydata[] = "Hello, world!";
static osjob_t sendjob;

// Schedule TX every this many seconds (might become longer due to duty
// cycle limitations).
const unsigned TX_INTERVAL = 60;

// Pin mapping
const lmic_pinmap lmic_pins = {
    .nss = 10,
    .rxtx = LMIC_UNUSED_PIN,
    .rst = 5,
    .dio = {2, 3, LMIC_UNUSED_PIN},
};

void printHex2(unsigned v) {
    v &= 0xff;
    if (v < 16)
        Serial.print('0');
    Serial.print(v, HEX);
}

void onEvent (ev_t ev) {
    Serial.print(os_getTime());
    Serial.print(": ");
    switch(ev) {
        case EV_SCAN_TIMEOUT:
            Serial.println(F("EV_SCAN_TIMEOUT"));
            break;
        case EV_BEACON_FOUND:
            Serial.println(F("EV_BEACON_FOUND"));
            break;
        case EV_BEACON_MISSED:
            Serial.println(F("EV_BEACON_MISSED"));
            break;
        case EV_BEACON_TRACKED:
            Serial.println(F("EV_BEACON_TRACKED"));
            break;
        case EV_JOINING:
            Serial.println(F("EV_JOINING"));
            break;
        case EV_JOINED:
            Serial.println(F("EV_JOINED"));
            {
              u4_t netid = 0;
              devaddr_t devaddr = 0;
              u1_t nwkKey[16];
              u1_t artKey[16];
              LMIC_getSessionKeys(&netid, &devaddr, nwkKey, artKey);
              Serial.print("netid: ");
              Serial.println(netid, DEC);
              Serial.print("devaddr: ");
              Serial.println(devaddr, HEX);
              Serial.print("AppSKey: ");
              for (size_t i=0; i<sizeof(artKey); ++i) {
                if (i != 0)
                  Serial.print("-");
                printHex2(artKey[i]);
              }
              Serial.println("");
              Serial.print("NwkSKey: ");
              for (size_t i=0; i<sizeof(nwkKey); ++i) {
                      if (i != 0)
                              Serial.print("-");
                      printHex2(nwkKey[i]);
              }
              Serial.println();
            }
            // Disable link check validation (automatically enabled
            // during join, but because slow data rates change max TX
	    // size, we don't use it in this example.
            LMIC_setLinkCheckMode(0);
            break;
        /*
        || This event is defined but not used in the code. No
        || point in wasting codespace on it.
        ||
        || case EV_RFU1:
        ||     Serial.println(F("EV_RFU1"));
        ||     break;
        */
        case EV_JOIN_FAILED:
            Serial.println(F("EV_JOIN_FAILED"));
            break;
        case EV_REJOIN_FAILED:
            Serial.println(F("EV_REJOIN_FAILED"));
            break;
        case EV_TXCOMPLETE:
            Serial.println(F("EV_TXCOMPLETE (includes waiting for RX windows)"));
            if (LMIC.txrxFlags & TXRX_ACK)
              Serial.println(F("Received ack"));
            if (LMIC.dataLen) {
              Serial.print(F("Received "));
              Serial.print(LMIC.dataLen);
              Serial.println(F(" bytes of payload"));
            }
            // Schedule next transmission
            os_setTimedCallback(&sendjob, os_getTime()+sec2osticks(TX_INTERVAL), do_send);
            break;
        case EV_LOST_TSYNC:
            Serial.println(F("EV_LOST_TSYNC"));
            break;
        case EV_RESET:
            Serial.println(F("EV_RESET"));
            break;
        case EV_RXCOMPLETE:
            // data received in ping slot
            Serial.println(F("EV_RXCOMPLETE"));
            break;
        case EV_LINK_DEAD:
            Serial.println(F("EV_LINK_DEAD"));
            break;
        case EV_LINK_ALIVE:
            Serial.println(F("EV_LINK_ALIVE"));
            break;
        /*
        || This event is defined but not used in the code. No
        || point in wasting codespace on it.
        ||
        || case EV_SCAN_FOUND:
        ||    Serial.println(F("EV_SCAN_FOUND"));
        ||    break;
        */
        case EV_TXSTART:
            Serial.println(F("EV_TXSTART"));
            break;
        default:
            Serial.print(F("Unknown event: "));
            Serial.println((unsigned) ev);
            break;
    }
}

void do_send(osjob_t* j){
    // Check if there is not a current TX/RX job running
    if (LMIC.opmode & OP_TXRXPEND) {
        Serial.println(F("OP_TXRXPEND, not sending"));
    } else {
        // Prepare upstream data transmission at the next possible time.
        LMIC_setTxData2(1, mydata, sizeof(mydata)-1, 0);
        Serial.println(F("Packet queued"));
    }
    // Next TX is scheduled after TX_COMPLETE event.
}

void setup() {
    Serial.begin(9600);
    Serial.println(F("Starting"));

    #ifdef VCC_ENABLE
    // For Pinoccio Scout boards
    pinMode(VCC_ENABLE, OUTPUT);
    digitalWrite(VCC_ENABLE, HIGH);
    delay(1000);
    #endif

    // LMIC init
    os_init();
    // Reset the MAC state. Session and pending data transfers will be discarded.
    LMIC_reset();

    // Start job (sending automatically starts OTAA too)
    do_send(&sendjob);
}

void loop() {
    os_runloop_once();
}

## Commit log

2020-02-18 add photo of the bests antennas
2020-02-18 PCB-antenna is not optimal
2020-02-27 gasket antenna will be to big
2020-02-27 found the antenna
2020-03-01 design PCB antenna
2020-03-03 add inkcape design from antenna
2020-03-03 add picture of antenna_drawing
2020-03-08 draw the PCB for a part
2020-03-10 add antenna
2020-03-10 try to print on mika -- failed
2020-03-11 add zip for making pcb
2020-03-15 add partlist for prototype
    [Prototype.csv]
2020-03-29 solder and test antenna
2020-04-06 solder the board with module
2020-04-11 connect the arduino and RF95 for testing
2020-04-21 test the board with the board of Niels - Succcesful
2020-04-27 test with better antenna on the gateway
2020-05-04 change PCB antenna to the best dimensions
    [untitled.brd, untitled.sch]
2020-05-08 different between the two antenna's
2020-05-09 add eagle stuff
    [untitled.brd, untitled.sch]
2020-05-09 remove some old stuff
    [untitled.brd, untitled.sch]
2020-05-09 add schematic
    [Prototype.csv]
2020-05-09 replace PCB
2020-05-09 change name folder
    [untitled.brd, untitled.sch]
2020-05-11 add some old stuff
    [Prototype.csv]

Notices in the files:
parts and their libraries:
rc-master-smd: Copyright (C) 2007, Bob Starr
